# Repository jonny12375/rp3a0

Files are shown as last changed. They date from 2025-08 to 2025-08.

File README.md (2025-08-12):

# RP3A0 reverse engineering

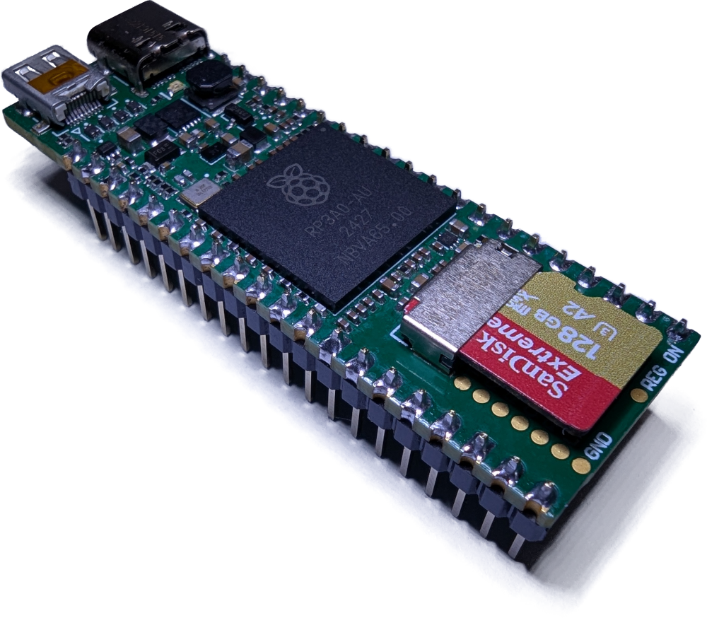
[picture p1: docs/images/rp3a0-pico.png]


This contains my attempts at reverse-engineering the RP3A0 SoC from the Raspberry Pi Zero 2W so I can place it on my own PCB.

I plan to eventually use this in another project, but for now I need a proof of concept. I decided to make the most cursed thing I could think of, Pi Pico sized board, but with a full Raspberry Pi processor on it. It has basically the same pinout as a Pi Pico, all the GPIOs that match up are in the same position. HDMI is sketchy, there's no Wi-Fi, and USB-C is a bit weird, but it boots and I can get it online. Check the [`breakout/rp3a0_mini`](breakout/rp3a0_mini) dir for this.

## Documentation:
* [`docs`](docs) - The pinout of the RP3A0 SoC, and how I reverse engineered it
* [`docs/reballing`](docs/reballing.md) - How to harvest the RP3A0 from a Raspberry Pi Zero 2W and prepare it for soldering onto a PCB
* [`breakout/rp3a0_mini`](breakout/rp3a0_mini) contains an Altium project for the RP3A0 Pico, a carrier board in almost the same form factor as the Pi Pico
* [`library`](library) contains an Altium library with the SoC footprint and the outline of the castellated pads for a Pi Pico

## Disclaimer
This was a stupid idea and you probably shouldn't do it. There are heaps of other Linux SoCs you can use, an especially ones that aren't a 21x21 BGA device with no public documentation. It's also not super easy to solder, so you might trash a couple parts trying to get it right.

## Thanks to...
* My coworkers for putting up with me asking questions about BGA reballing and PCB design
* Jeff Geerling ([YouTube](https://www.youtube.com/c/JeffGeerling), [website](https://www.jeffgeerling.com/)) for:
  * his blog post with an [X-Ray of the Pi Zero 2W](https://www.jeffgeerling.com/blog/2021/look-inside-raspberry-pi-zero-2-w-and-rp3a0-au) that inspired this project
  * being cool when I ambushed him at Open Sauce 2025 to show him my crazy project
  * being the first person to test out my prototype board, giving me feedback and providing some great photos for me to use
* Raspberry Pi for making such a great little SoC, and at least releasing _some_ schematics for it

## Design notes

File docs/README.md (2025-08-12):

# Reverse engineering the RP3A0

## tl;dr - RP3A0 pinout

The RP3A0 a 21x21 BGA package with 0.65mm pitch, outside dimensions are 15x15mm. I haven't measured the pad size accurately, but I'm using 0.3mm solder balls when reballing it.

Here's the pinout of the RP3A0 SoC (as far as I can tell). All the names here are ones I've given to the pins. They're labelled as to what they do on a Pi Zero 2W, not what the function is internally.
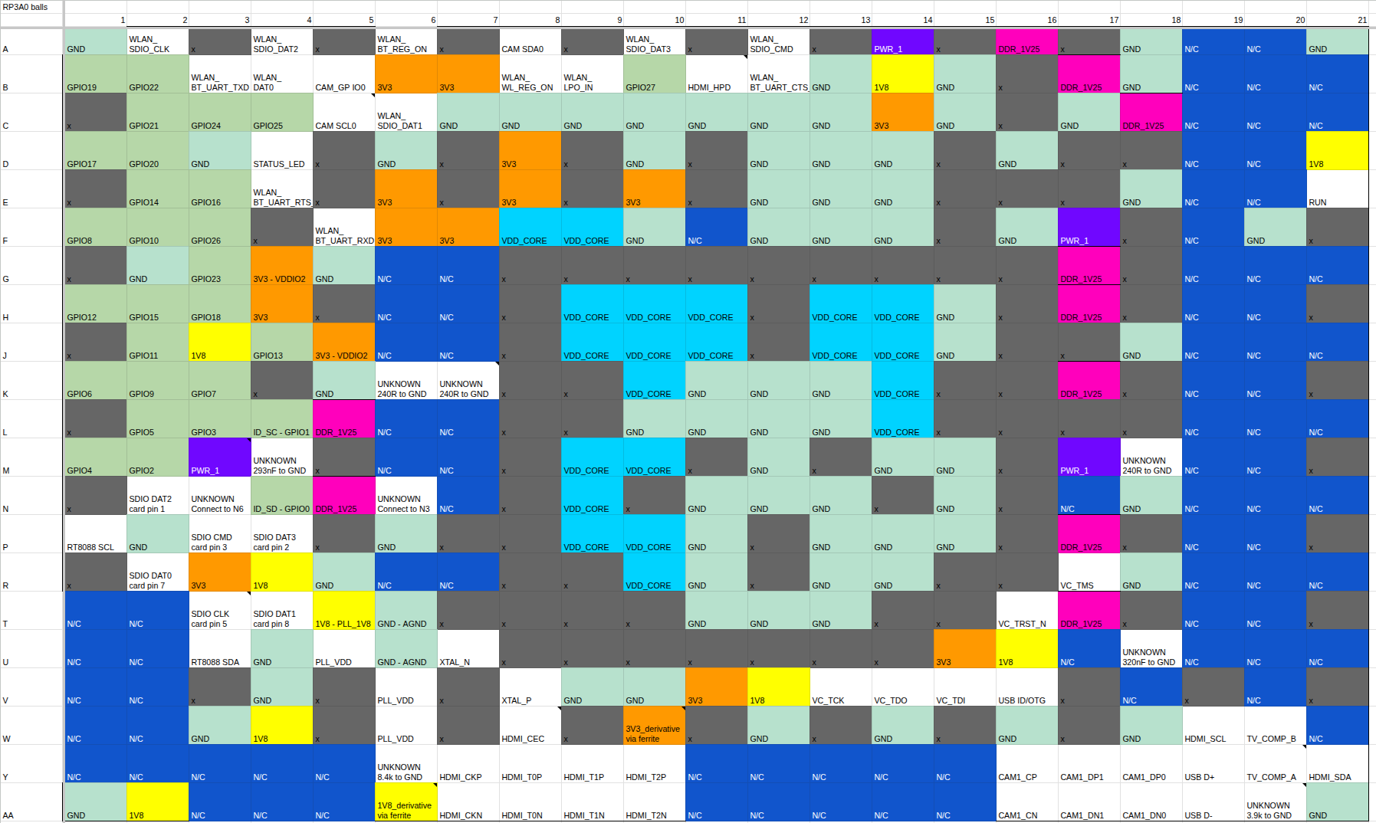
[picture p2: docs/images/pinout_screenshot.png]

You can check out the Google Sheet with the pinout here: [RP3A0 balls](https://docs.google.com/spreadsheets/d/1cQo1mM0g4L-HjAe8-86Zw-xbBoLv0I49Cb5mO69Yzt8/edit?usp=sharing) or check the schematics for my breakout board [`breakout/rp3a0_mini/outputs/rp3a0-pico-schematics-v1.1.pdf`](../breakout/rp3a0_mini/outputs/rp3a0-pico-schematics-v1.1.pdf).

There are a bunch of unknown pins, so all I've done is hooked them up in the same way that they are on the Pi Zero 2W. The reduced schematics that are published do show some pins on the SoC, so those were easy to label.

Note: Pins on a BGA are denoted with a letter and a number, where the letter is the row and the number is the column. BUT, not all letters are used when labelling BGA pins to avoid confusion. The letters `I, O, Q, S, X and Z` are skipped, and then it rolls over to `AAx`, `ABx`. This confused me at first when the reduced schematics had the crystal connected to U7 and V8 but from my pinout it was on Q7 and R8. 

Want to learn how to solder the RP3A0? Check out [reballing the RP3A0](reballing.md)

## Why?
There's another project I've been working on for years (that I'll probably document at some point in the future), but I wanted to add a linux processor to it. 
However it's pretty space constrained and I didn't want to have to do traces for DDR, so I was looking for an SoC that had a decent amount of RAM baked in, or a decent SoM. Unfortunately, most SoMs I found have parts on the other side as well, meaning I'd have to have a cutout in whatever board I was putting it on.

Here's a few of the options I was looking at:
* Allwinner F1C100s/F1C200s SoC
  * QFN package is easy to solder 
  * Doesn't have a huge amount of RAM (32MiB/64MiB)
* Rockchip RV1103/6 SoC
  * QFN package is easy to solder
  * Has a decent amount of RAM (128MiB)
  * Not a lot of software support, but I could probably get it working
* MangoPi mCore-R818 SoM
  * Powerful, heaps of RAM
  * Has parts on the other side so needs a cutout in the board
  * Pretty big at 32x32mm, hard to find that much space in a square in the form factor I need
* Pi Compute module
  * Very powerful
  * Gets pretty thick with the connectors
* Raspberry Pi Zero 2W
  * Fairly powerful
  * VERY well supported
    * Easy to build a kernel for it
    * Heaps of software support
  * Won't fit at all in the space I have
  * If only I could use the processor on its own...
* RP3A0
  * Fairly powerful
  * Has 512MiB of RAM baked in
  * VERY well supported
  * Only reduced schematics available
  * 21x21 BGA package, not easy to solder
  * Only available on the Pi Zero 2W
  * Sounds like a fun challenge though

## Equipment I used
* Hot air rework station: anything will be better than what I've got
* Soldering iron: Hakko FX-888D
* Flux: Chipquik NC191
* Hot plate: I got this one from AliExpress: [link](https://www.aliexpress.com/item/1005005576574932.html). I haven't tried the smaller USB-C powered ones, this one is pretty good, though it has some serious thermal mass so it takes a little bit to heat up, but also takes FOREVER to cool down.
* Microscope: I can't find the exact one I bought, but again from AliExpress: [link](https://www.aliexpress.com/item/1005008174025268.html). Having both HDMI and USB was super useful for this project. The HDMI output is much lower latency, so it's totally possible to look just at my monitor when soldering under it. The USB output just shows up as a webcam on a computer, so I used VLC to stream the video feed and used that to capture screenshots.
* Sandpaper: I used 800, 1200 and 2000 grit, but you could probably get away with just 800 and 1200
* Glass plate: I used an old glass 3D printer bed, but any flat piece of glass will do
* Tweezers: Mine are the ones that come in the iFixit Pro Tech Toolkit

## How?
There are only [reduced schematics](https://datasheets.raspberrypi.com/rpizero2/raspberry-pi-zero-2-w-reduced-schematics.pdf) available for the Pi Zero 2W, which fortunately gives all the details about the power supplies, but not much else. To figure out the rest I was going to have to follow the traces on the PCB. Unfortunately, it's a 6-layer PCB, so there's going to be a lot that I can't figure out without going in deeper. If I had a CNC mill I might have tried to use that to shave down the board, but surely just using sandpaper won't take too long, right?

I wanted to be able to keep track of all of the different parts on the board, just in case I needed to re-use or re-measure any of them. I printed out a photo of the board and covered it in double-sided tape, and put each part I took off the board back onto the same location on the board. I used hot air to remove the parts at the start, but it was definitely harder than expected given the lead-free solder that's used. I managed to pull some pads off the board when taking the SoC off, fortunately they weren't connected to anything. Later on in the project I bought a small hot-plate that made taking parts off MUCH easier.
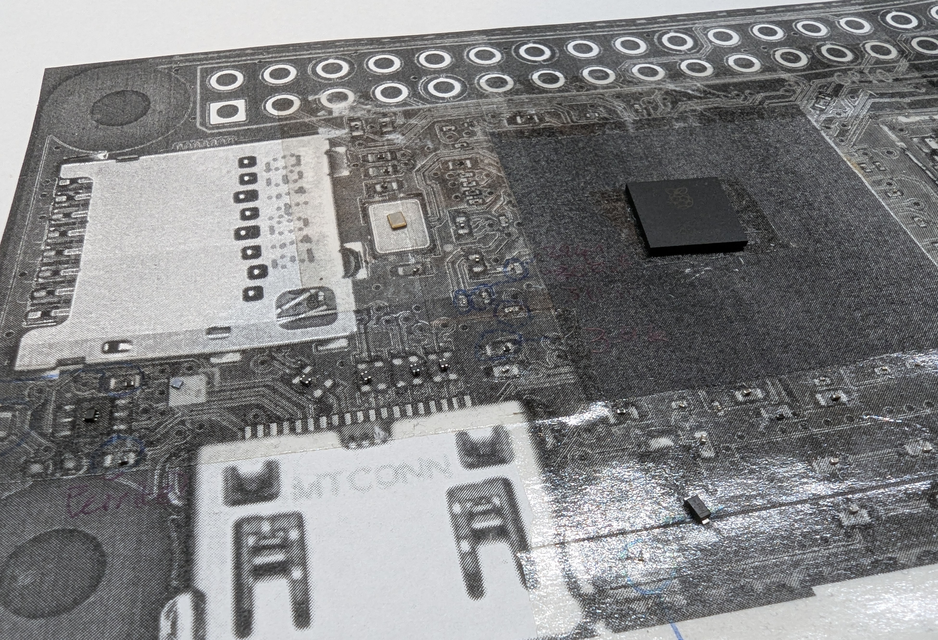
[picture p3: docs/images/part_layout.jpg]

My highly sophisticated parts organisation system. Some of passives are tiny 0201 packages, I definitely lost a few of them while trying to measure them, so I had to take a guess.

I started off with some other boards that I had lying around to test out the process. I figured I needed a super flat surface to start with, so I used an old glass 3d printer bed I had. I bought 800, 1200 and 2000 grit sandpaper from the hardware store, along with some gloves since I knew it was going to get messy. Since it's sanding fibreglass, you should be more careful than I was and wear a mask. Since I was wet sanding it didn't create a lot of dust in the air.
I cut out bits of the sandpaper, taped it down to the glass, wet the sandpaper and started sanding the board. At first I just needed to get through the soldermask on both sides to get a better look at the traces underneath, and that only took a couple minutes before all I had was bare copper.

To then get an image of the copper, I tried the flatbed scanner that's in my Brother printer, but it's resolution wasn't great. I probably could have worked out the traces from it, but it was still pretty blurry. The microscope I have only has a 27mmx15mm field of view at the lowest magnification, so I couldn't get a full image of the board at once. I ended up making a simple jig to hold the board in place with notches in it so I could move the board between the notches reliably to take a photo of one horizontal segment. Then I moved the board down a little bit leaving an overlap of about a third of the board, and took captures of the next horizontal segment.
I tried a bunch of tools that could supposedly do all the stitching for me, like Hugin and https://github.com/OpenStitching/stitching. However, I just couldn't get anything to work reliably, and I was spending more time than it would have taken me to just stitch it myself. Instead, I imported each image into GIMP then used the Unified Transform tool to rotate/scale/change perspective of each image to line up the vias from the microscope image with the vias in the image from the flatbed scanner. 

I changed between the sandpaper as I went depending on how much material I needed to remove. Usually the 800 grit was fine. It's quite a slow process, and also quite hard to get the board to sand down evenly. I was checking the board every so often, and if it was wearing unevenly I'd apply more pressure to an area, or even give the board a bit of a bend. It would keep its shape just enough focus on a particular area without sanding down areas that were already well exposed.

## Results
The process was very slow - I ended up sanding and capturing one layer per night after work. But the results are worth it! After stitching all the images together, I ended up with a full set of 6 layers of the Pi Zero 2W PCB. The stitching isn't perfect, but the main thing I wanted was to reliably have all the vias lined up so I'd be able to follow the traces between layers. I also made sure to capture the top layer with the soldermask sanded off, so I could see all the traces and pads clearly.
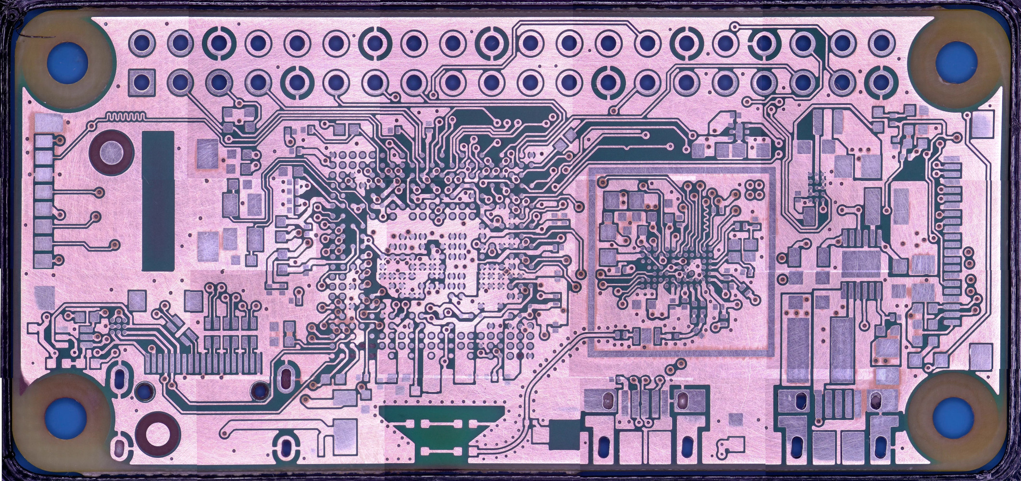
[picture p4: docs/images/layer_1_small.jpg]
The top layer with soldermask sanded off


High resolution layers - (~5MB JPGs)!
* [Top with soldermask and silkscreen](images/layer_1_soldermask.jpg)
* [Layer 1](images/layer_1.jpg)
* [Layer 2](images/layer_2.jpg)
* [Layer 3](images/layer_3.jpg)
* [Layer 4](images/layer_4.jpg)
* [Layer 5](images/layer_5.jpg)
* [Layer 6](images/layer_6.jpg)
* [Bottom with soldermask and silkscreen](images/layer_6_soldermask.jpg)

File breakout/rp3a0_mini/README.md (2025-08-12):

# RP3A0 Pico

This contains the Altium project for the RP3A0 Pico, a Pi Pico sized board with the RP3A0 SoC on it. 

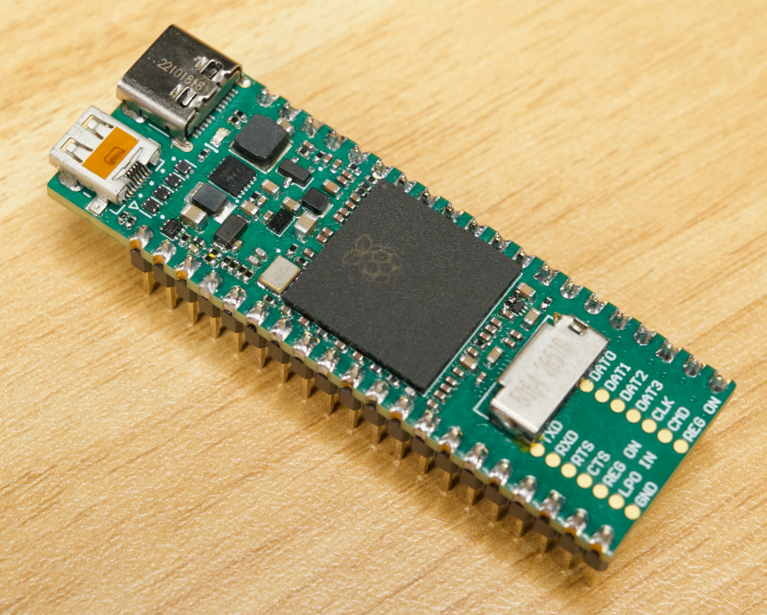
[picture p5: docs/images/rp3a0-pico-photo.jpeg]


## Goals
* Prove that I have the RP3A0 SoC pinout
* Create a board that could actually be useful where you need a more powerful processor in a small form factor
* Staying close to the Pi Pico form factor, with the same castellated pads and no parts on the underside

## Errata v1.1
This is definitely a V1 - this is the first board I've had built of this design.  
* I spent no time on the HDMI, so it doesn't work super well. I have managed to get 1080p@60Hz video out of it, but it didn't work well on some monitors. With some proper trace layout and impedance matching it should work better.
* The ports are far too close together, but I didn't have enough space if I wanted to keep the same width as a Pico. In the next revision I'm going to try out rotating the HDMI connector 90 degrees to point out the side.
* There is no Wi-Fi or Bluetooth. There's not a huge amount of space on the board, but I left test pads for all the signals from the RP3A0. It may be possible to transfer over the layout from the Pi Zero 2W but there would be no space for an on-board antenna. The part is a finer pitch than the RP3A0, so reballing it will be difficult.
* The ID pin that would normally go to the micro USB connector is only connected to a test pad on the underside. I'm not sure if this makes a big difference in reality, since I've been able to use it as a USB host just fine. In case you do need the functionality, you can bridge the pads of J4 on the bottom side to connect ID to GND.
* I haven't tested this in any Pi Pico breakout boards, so there's a chance some pins don't match up. I'd recommend checking the pinout against the schematic of the breakout board before plugging it in.
* I didn't connect VSYS to VBUS with a diode, so the 5V pin (pin 40) goes directly to the 5V rail. There's no overvoltage or reverse polarity protection. Also I didn't connect pin 39 (labelled VSYS on a Pico) to anything, so if something takes power from it, it won't work. You could bridge them together with solder.
* Not all the values on the schematics are correct, I've tried to update the BOM CSV with the notes I took when building the board

## Important links
* Schematic PDF - [outputs/rp3a0-pico-schematics-v1.1.pdf](outputs/rp3a0-pico-schematics-v1.1.pdf)
* Draftsman PDF - [outputs/rp3a0-pico-draftsman-v1.1.pdf](outputs/rp3a0-pico-draftsman-v1.1.pdf)
* Gerber files - [outputs/rp3a0-pico-gerbers-v1.1.zip](outputs/rp3a0-pico-gerbers-v1.1.zip)
  * I had this built by JLCPCB, remember to add the option for castellated pads on two sides.
* BOM CSV - [outputs/rp3a0-pico-bom-v1.1.csv](outputs/rp3a0-pico-bom-v1.1.csv)

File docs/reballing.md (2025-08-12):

# Harvesting and reballing the RP3A0 SoC

## Can I just buy the RP3A0?
No, you can't. The RP3A0 is not available for purchase separately, but you can harvest it from a Raspberry Pi Zero 2W.

## Harvesting the RP3A0
This is the process I followed. It might not be the best way to do it, but it worked for me. Don't @ me complaining about all the Pi boards you destroy trying to do this.

You're going to need:
* A hotplate or a hot air rework station
  * I used hot air for this initially, but once I got the hotplate, I found it much easier. The tiny USB-C powered ones are probably good enough
* A good soldering iron
* Good flux - e.g. Chipquik NC191
* Solder wick
* Tweezers and/or a vacuum pickup tool
* Solder balls - 0.3mm for the RP3A0. Make sure it's leaded solder, lead-free is much harder to work with
* Solder
* A reballing stencil - 0.65mm pitch, 21x21 BGA, 0.3mm balls
  * You could use one of those fancy ones that holds the IC in and collects all the solder balls, but I just used a small stencil from a pack on AliExpress 
* A microscope is super useful
* A donor Pi Zero 2W

1. Put the Pi Zero 2W on the hotplate and heat it up to about 230C. Adding some flux to the SoC should help it come off easier. If you're using hot air - you're going to need a lot of heat. Go slowly and try not to rip any pads off.
2. Use some tweezers or a vacuum pickup tool to try and lift the SoC off the board. 
3. Turn the hotplate off and let the SoC cool down.
4. Add some flux to the bottom of the SoC and clean up the solder off the pads with solder wick. Adding some leaded solder to the pads will make this easier. Make sure all the pads are clean and have no solder on them.
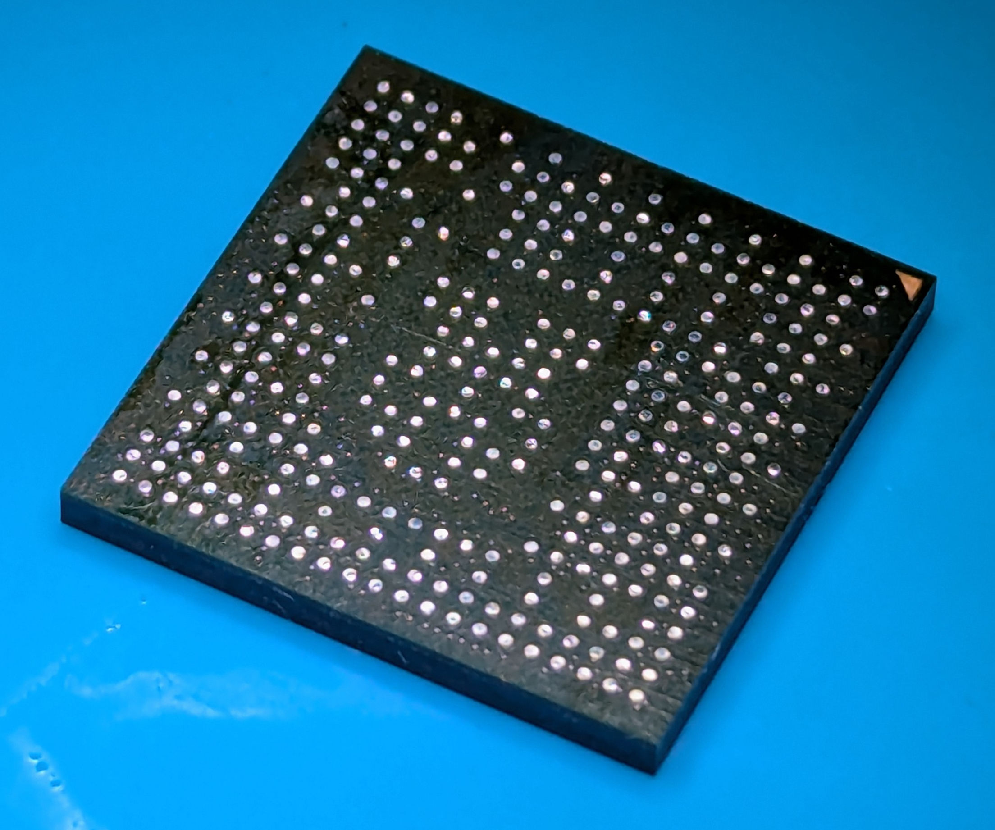
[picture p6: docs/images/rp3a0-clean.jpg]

It should look something like this
5. Apply a VERY thin layer of flux to the bottom of the SoC, and then place it on the stencil. Line up the holes in the stencil with the pads on the SoC.
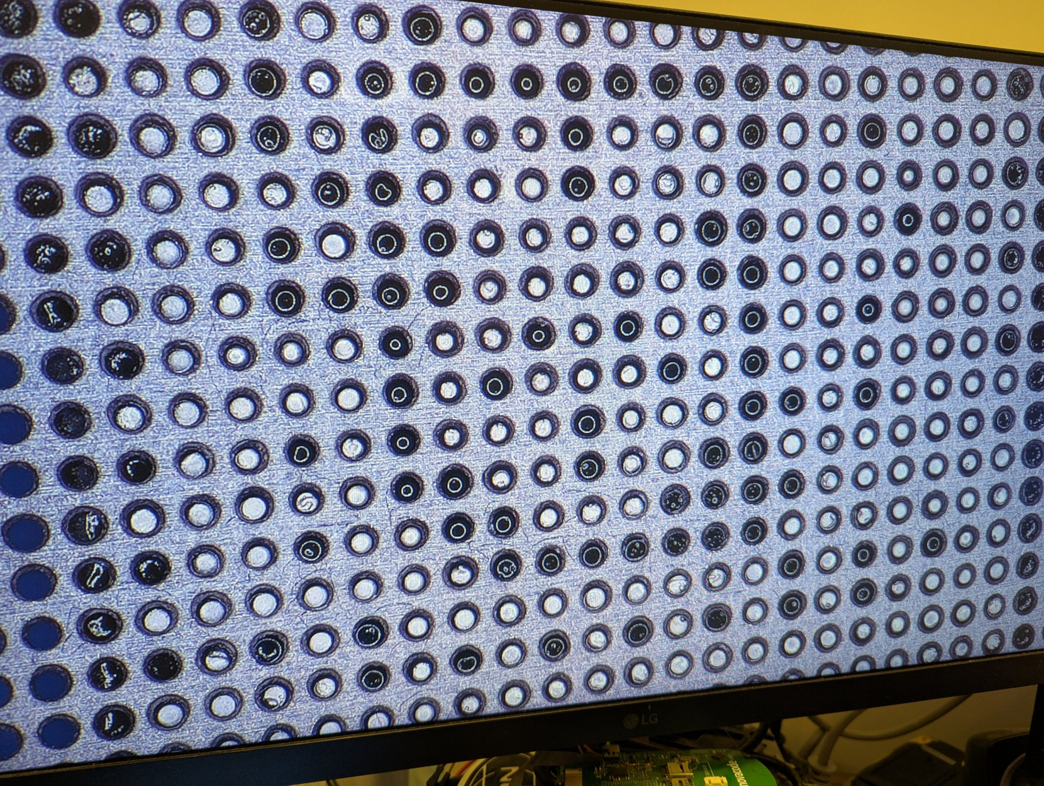
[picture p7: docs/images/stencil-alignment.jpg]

6. My flux was tacky enough to hold the stencil in place, but if yours isn't, you can use some tape to hold the SoC in place.
7. Find a shallow dish to put the stencil in. This is to catch all the solder balls that fall out.
8. Put the stencil in the dish with the holes facing up, and sprinkle some solder balls into the holes. Shake the stencil gently to spread the balls out. A card is also useful here to distribute them, but it also makes it easy to feel where there are two balls in one hole.
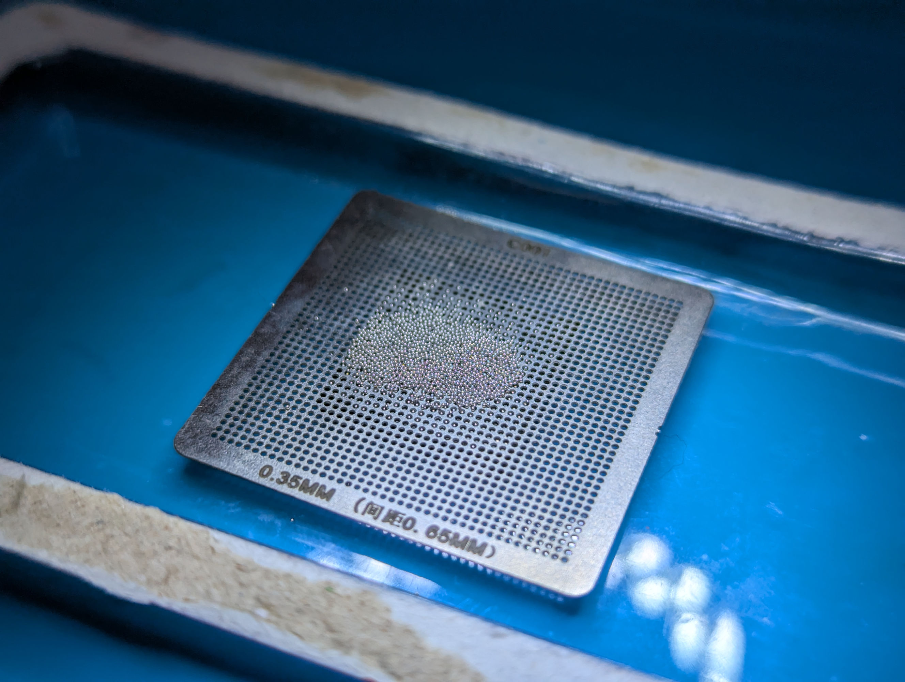
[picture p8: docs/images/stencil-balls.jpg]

9. You should only have one ball in each hole. If there is more than one, you'll end up with a pad that's got too much solder on it, and it will either lift the part up so it doesn't solder correctly, or cause a short.
10. Put the SoC (still stuck to the stencil) on the cold hotplate with the balls up, and turn the hotplate on to about 200C. You should see the solder balls melt and drop into place. If any don't drop into place, you may be able to carefully poke them in with tweezers. If the flux bubbles up and sends the balls everywhere, then you put too much flux on and you'll need to start again.
11. Once all the balls are in place, turn the hotplate off and let it cool down.
12. VERY carefully peel the stencil off the SoC. Don't force it if it's not coming, you may be able to heat it up a little bit to make the flux more liquid.
13. Inspect the SoC to make sure all the balls are in place and there are no shorts. If there's a ball missing, you're going to have to start again.
14. There will likely be some balls stuck to the SoC with flux that aren't supposed to be there. Using a little bit of Isopropyl alcohol and a toothbrush, gently brush the bottom of the SoC to remove them. You can refer to the pinout above to see which pads are supposed to have solder.

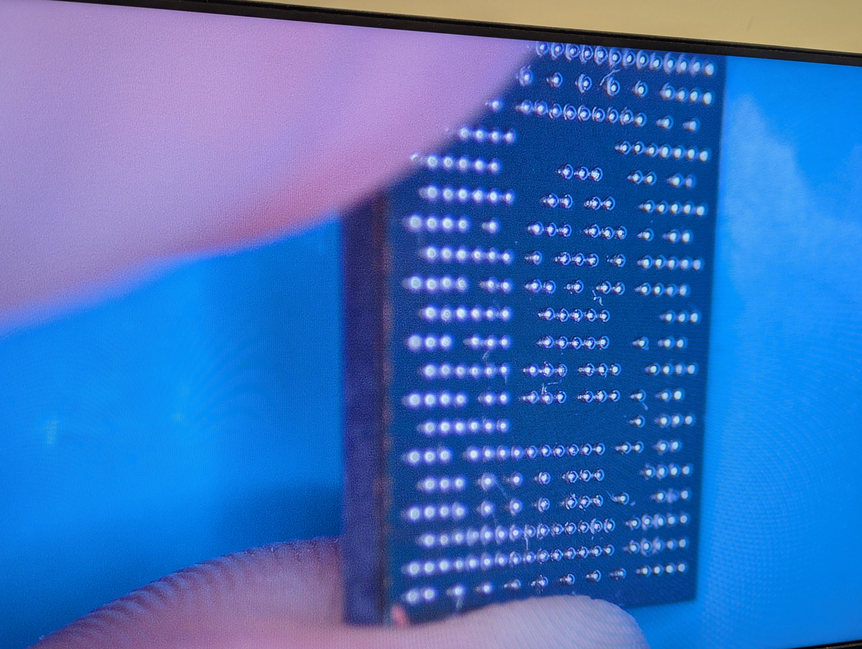
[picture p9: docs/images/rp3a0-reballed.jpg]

Great, now you have a re-balled RP3A0 SoC!

## Soldering the RP3A0

1. Clean the pads on the PCB, if there's solder, clean it all off with solder wick.
2. Add a small layer of flux to the area
3. Place the RP3A0 on the pads, making sure to line it up as close as you can. When reflowing it will move into place, but only if it's close in the first place.
4. Put the PCB on the hotplate and turn it on to about 200C.
5. As it heats up, keep an eye on it. The flux should start bubbling and smoking, then hopefully the RP3A0 will jump into place. 
6. If you want, you can VERY carefully give it a little poke with tweezers to check it's in place. If it is, turn the hotplate off and let it cool down.
7. Good luck! If it didn't work, then you get to do it all again.

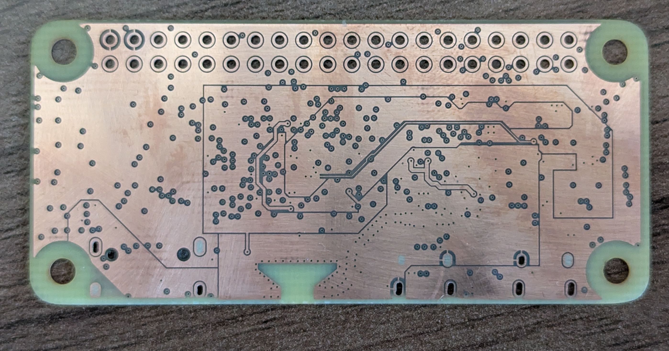
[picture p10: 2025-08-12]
docs/images/pcb_sanded.jpg

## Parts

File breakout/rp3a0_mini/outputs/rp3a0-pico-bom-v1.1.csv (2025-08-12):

Name | Designator | Quantity | Value | Footprint | Description | Comment | Link
Cap | C1, C2, C5, C8, C18, C20, C21, C22, C23, C24, C26, C27, C28, C29, C30, C31, C32, C33, C34, C35, C37, C39, C40, C41, C42, C44, C45, C46 | 28 | 220n | CAP-0402 | Capacitor 0402
Cap | C3, C4, C11, C13, C16, C17 | 6 | 10u | CAP-0603 | Capacitor 0603
Cap | C6, C9 | 2 | 18p | CAP-0402 | Capacitor 0402
Cap | C7, C10 | 2 | 1u | CAP-0402 | Capacitor 0402
Cap | C12, C14 | 2 | 47u | C0805 NP | Capacitor 0805 |  | https://www.lcsc.com/product-detail/C16780.html
Cap | C15, C19, C47 | 3 | 100n | CAP-0402 | Capacitor 0402
Cap | C25 | 1 | 100p | CAP-0402 | Capacitor 0402 | Not super sure on this value, 100pF works
Cap | C36, C38, C43 | 3 | 4.7u | CAP-0603 | Capacitor 0603 |  | https://www.lcsc.com/product-detail/C1705.html
SMD_LED | D1 | 1 |  | LED_0603 | 0603 LED
DFLS130LQ-7 | D2 | 1 |  | DIO_DFLS130LQ-7 | Diode Schottky 1A 30V PowerDI 123 | Diodes Inc DFLS130LQ-7
EXC-24CG900U | FL1, FL2, FL3, FL4 | 4 |  | FIL_EXC24CB102U | Common mode Filters(for Gbps) | Couldn’t find the original part I spec’d, switched to PANASONIC EXC24CH900U | https://www.lcsc.com/product-detail/C236275.html
MOLEX-0475710001 | J1 | 1 |  | MOLEX_0475710001 | 9 _8 + 1_ Position Card Connector Secure Digital - microSD™ Surface Mount, Right Angle Gold | Couldn’t find the original part, switched to Molex 473092651 | https://www.lcsc.com/product-detail/C587826.html
MOLEX-467652301 | J2 | 1 |  | MOLEX_467652301 | 0.40mm Pitch Micro HDMI Connector, Right-Angle Receptacle, Surface Mount |  | https://www.lcsc.com/product-detail/C6961796.html
105450-0101 | J3 | 1 |  | MOLEX_105450-0101 | USB-C, USB 3.1 Gen 2, Receptacle Connector 24 Position Surface Mount, Right Angle; Through Hole |  | https://www.digikey.com/en/products/detail/molex/1054500101/5843890
INDUCTOR | L1 | 1 | 470nH | INDC2016X100N | SRP2010-R47M inductor |  | https://www.digikey.com/en/products/detail/bourns-inc/srp2010-r47m/4876856
INDUCTOR | L2 | 1 | 4.7uH | INDP4040X180N | BOURNS SRN4030HA-4R7Y |  | https://www.lcsc.com/product-detail/C5926030.html
INDUCTOR | L3 | 1 | 2.2uH | INDP2622X120N | BOURNS SRN2512-2R2M |  | https://www.lcsc.com/product-detail/C2041574.html
INDUCTOR | L4, L5, L6 | 2 | 220R | CAP-0402 | Ferrite bead SMD |  | https://www.lcsc.com/product-detail/C85813.html
DMG2305UX-7 | Q1 | 1 |  | SOT91P240X110-3N_DMG2305UX-7 | DIODES DMG2305UX-7 P-Channel 20V 4.2A _Ta_ 1.4W _Ta_ Surface Mount SOT-23 |  | https://www.lcsc.com/product-detail/C150470.html
Res SMD | R1, R2, R21, R22, R23, R24 | 6 | 1k8 | RES-0402-SML | Resistor 0402
Res SMD | R3, R19, R20 | 3 | 100k | RES-0402-SML | Resistor 0402
Res SMD | R4 | 1 | 470k | RES-0402-SML | Resistor 0402
Res SMD | R5 | 1 | 82k | RES-0402-SML | Resistor 0402
Res SMD | R6 | 1 | 10k | RES-0402-SML | Resistor 0402
Res SMD | R7, R15, R25 | 3 | 47k | RES-0402-SML | Resistor 0402
Res SMD | R8 | 1 | 18k | RES-0402-SML | Resistor 0402
Res SMD | R9, R10 | 2 | 5.1k | RES-0402-SML | Resistor 0402
Res SMD | R11 | 1 | 470R | RES-0402-SML | Resistor 0402
Res SMD | R12, R13, R18 | 3 | 240R | RES-0402-SML | Resistor 0402
Res SMD | R14 | 1 | 33R | RES-0402-SML | Resistor 0402
Res SMD | R16 | 1 | 3.9k | RES-0402-SML | Resistor 0402
Res SMD | R17 | 1 | 1K | RES-0402-SML | Resistor 0402
RP3A0 | U1 | 1 |  | RP3A0-BGA | RP3A0-AU SoC | Only available on Pi Zero 2W boards, needs reballing after desoldering | https://www.raspberrypi.com/products/raspberry-pi-zero-2-w/
RT9081A-1BGQZA(2) | U2 | 1 |  | VREG_RT9081A_1BGQZA(2) | RT9081A-1BGQZA(2) Linear Voltage Regulator IC 1 Output 500mA 6-ZADFN (1.2x1.2) | Make sure you buy the 1.25V fixed regulator | https://www.digikey.com/en/products/detail/richtek-usa-inc/rt9081a-1bgqza-2/6676758
RT8088AWSC | U3 | 1 |  | 15B_WLCSP_1.31x2.11 | RT8088AWSC Buck Switching Regulator IC Positive Programmable 0.6V 1 Output 3A 15-UFBGA, WLCSP |  | https://www.digikey.com/en/products/detail/richtek-usa-inc/RT8088AWSC/5880503
PAM2306AYPKE | U4 | 1 |  | SON45P300X300X80-13N | PAM2306AYPKE Buck Switching Regulator IC Positive Fixed 1.8V, 3.3V 2 Output 1A 12-WFDFN Exposed Pad |  | https://www.lcsc.com/product-detail/C508236.html
DMG1024UV-7 | U5 | 1 |  | SOT50P162X60-6N | Dual N-Ch Enhancement MOSFET SOT-563 | Diodes Inc DMG1024UV-7 | Used DMN2004VK | https://www.lcsc.com/product-detail/C145115.html
ECS-192-18-33-JGN-TR | Y1 | 1 |  | XTAL_ECS-192-18-33-JGN-TR | 19.2MHz Crystal Oscillator |  | https://www.digikey.com/en/products/detail/ecs-inc/ECS-192-18-33-JGN-TR/6821628

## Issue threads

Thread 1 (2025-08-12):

First Prototype - Bringup issues

geerlingguy, 2025-08-12:
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

Just wanted to document here, since that way it can be documented _somewhere_. I was excited to receive a prototype from @jonny12375 at Open Sauce, and I have been testing it at my desk here:

- HDMI port is not functional (known issue)
- HDMI port and USB-C port are a little close together, meaning most of my plugs interfere with each other if I plug them both in at the same time (though some plugs are slim enough to work)
- 5V power via USB-C PD, USB-A to C, and direct to the 5V/GND pins via DC power supply worked fine, board consumed between 100-400 mA in my brief testing.
- Tried booting Pi OS 32-bit and 64-bit Lite and Desktop editions from a 32 GB microSD card, and it seemed to boot, but UART console would output nothing, but eventually after almost exactly 34 seconds every time, the kernel log would spit out 'rebooting' and it would restart.
- If I plugged my Debug Probe into the Pico's standard UART TX/RX pins, I would get some gibberish, so it *seems* like those pins ([pins 1/2 and GND](https://pico.pinout.xyz)) do something, but they didn't provide clean text output like GP14/GP15 (which are the [default on Pi GPIO](https://pinout.xyz))
- The SoC heated up to 55-58°C during this boot-and-reboot cycle, and the board was warm to the touch. Not much ground plane to dissipate the heat on there!

jonny12375, 2025-08-13:
Thanks for the submission and the coverage, @geerlingguy!

* I never managed to get HDMI working on the board you've got, but I've built up another one and I was able to get 1080p@60Hz out, but it definitely wasn't reliable. The routing of the HDMI traces is FAR from optimal, but I'm planning to fix that up on the next revision. I'll also try rotating the HDMI connector to point out the side to give a little more space.
* I'm going to flash clean Pi OS to an SD card and see if I can replicate the rebooting issue. The fact that it's printing that message out indicates the board has probably detected that somethings not right. Maybe related to the WiFi/BT IC being absent.
* The RP2040/2350's mapping for connecting peripherals to pins is far more configurable than the RP3A0. I initially opted for matching the GPIO numbers up instead of putting putting peripherals like UART and I2C on certain pins. This may make it hard if a breakout board is expecting UART or another peripheral like I2C or SPI on particular pins. I'll see whether there's a better layout to increase compatibility.
* GP0 and GP1 on the Pi Zero are ID_SD and ID_SC, on boot the RP3A0 tries to communicate using I2C on those pins to try and auto detect a HAT, so it makes sense you'd see something show up when connecting a UART adapter. Those pins aren't going to be very useful in a Pico form factor, so I might remove them if I shuffle the other pins around.

Tiersten, 2025-08-17:
> I never managed to get HDMI working on the board you've got, but I've built up another one and I was able to get 1080p@60Hz out, but it definitely wasn't reliable.

Y6 is HDMI_REF. R17 should be 8.4K but your BOM has 1K.

W10 is HDMI_3V3.
AA6 is HDMI_1V8.

K6/K7/M18 is ZQ/ZQ1 for SoC/RAM.

AA20 is USB_REF. C25 is 100pF.

zeankundev, 2025-09-06:
I think what @geerlingguy said that HDMI wasn't working, and after examination, those weren't routed in a differential pair manner. Looking forward on the next fix 😉

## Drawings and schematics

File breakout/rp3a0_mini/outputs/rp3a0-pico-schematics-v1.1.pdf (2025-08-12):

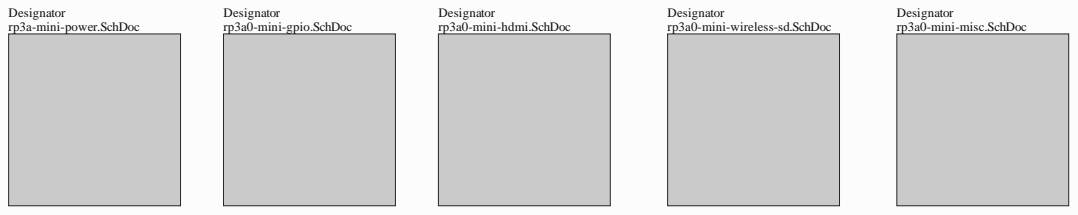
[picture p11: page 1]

Designator
rp3a0-mini-wireless-sd.SchDoc

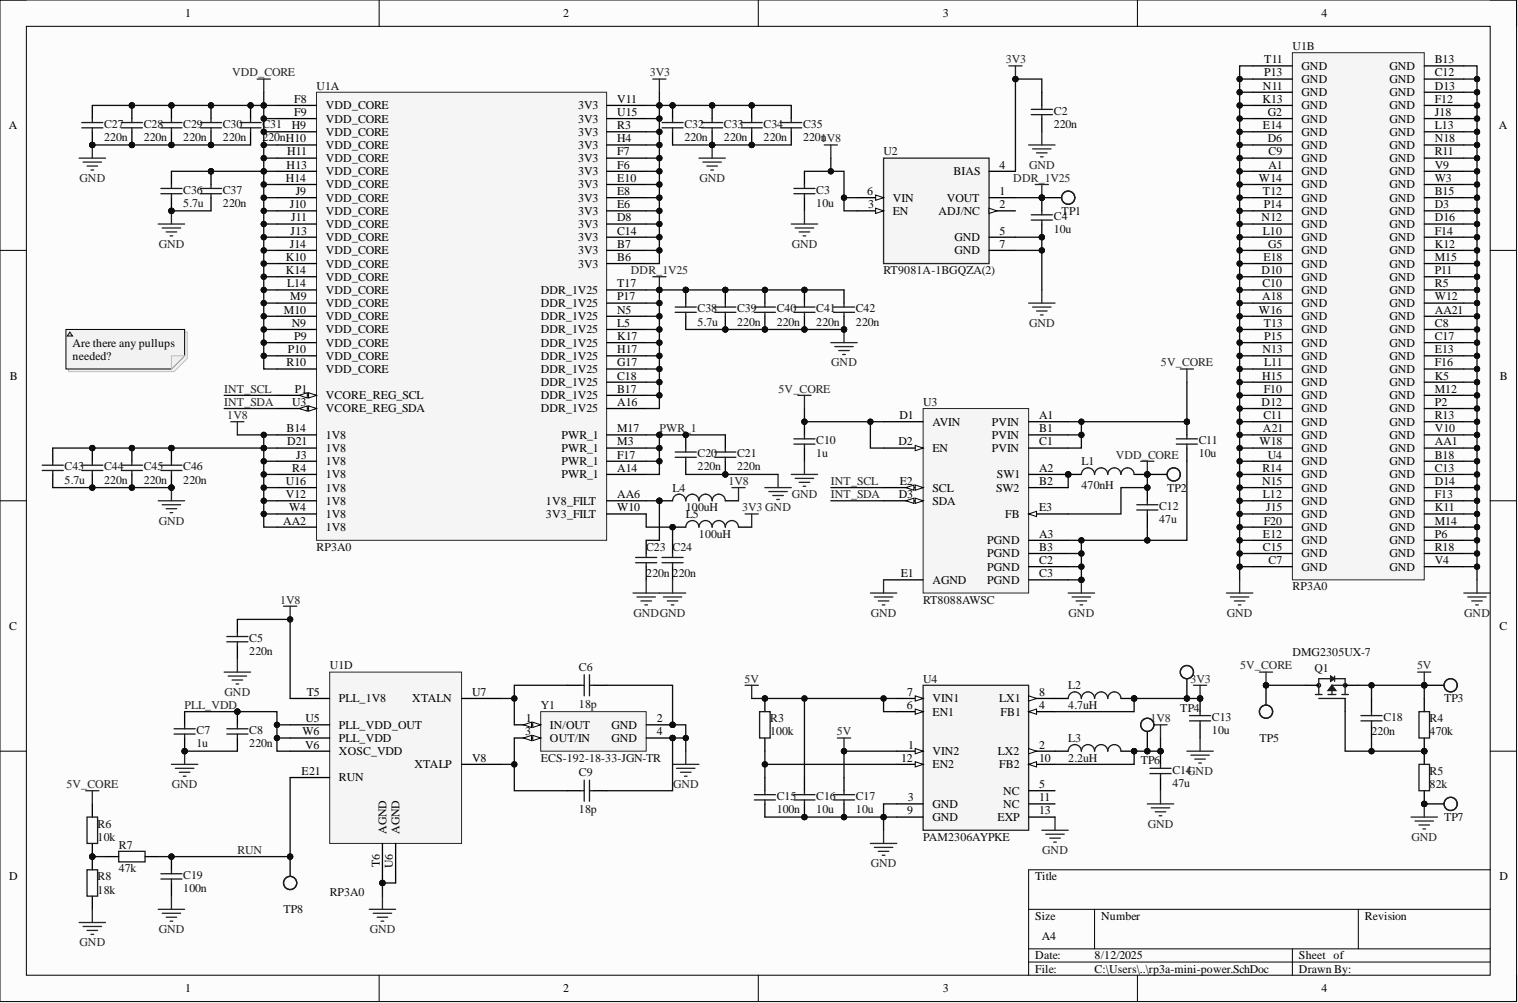
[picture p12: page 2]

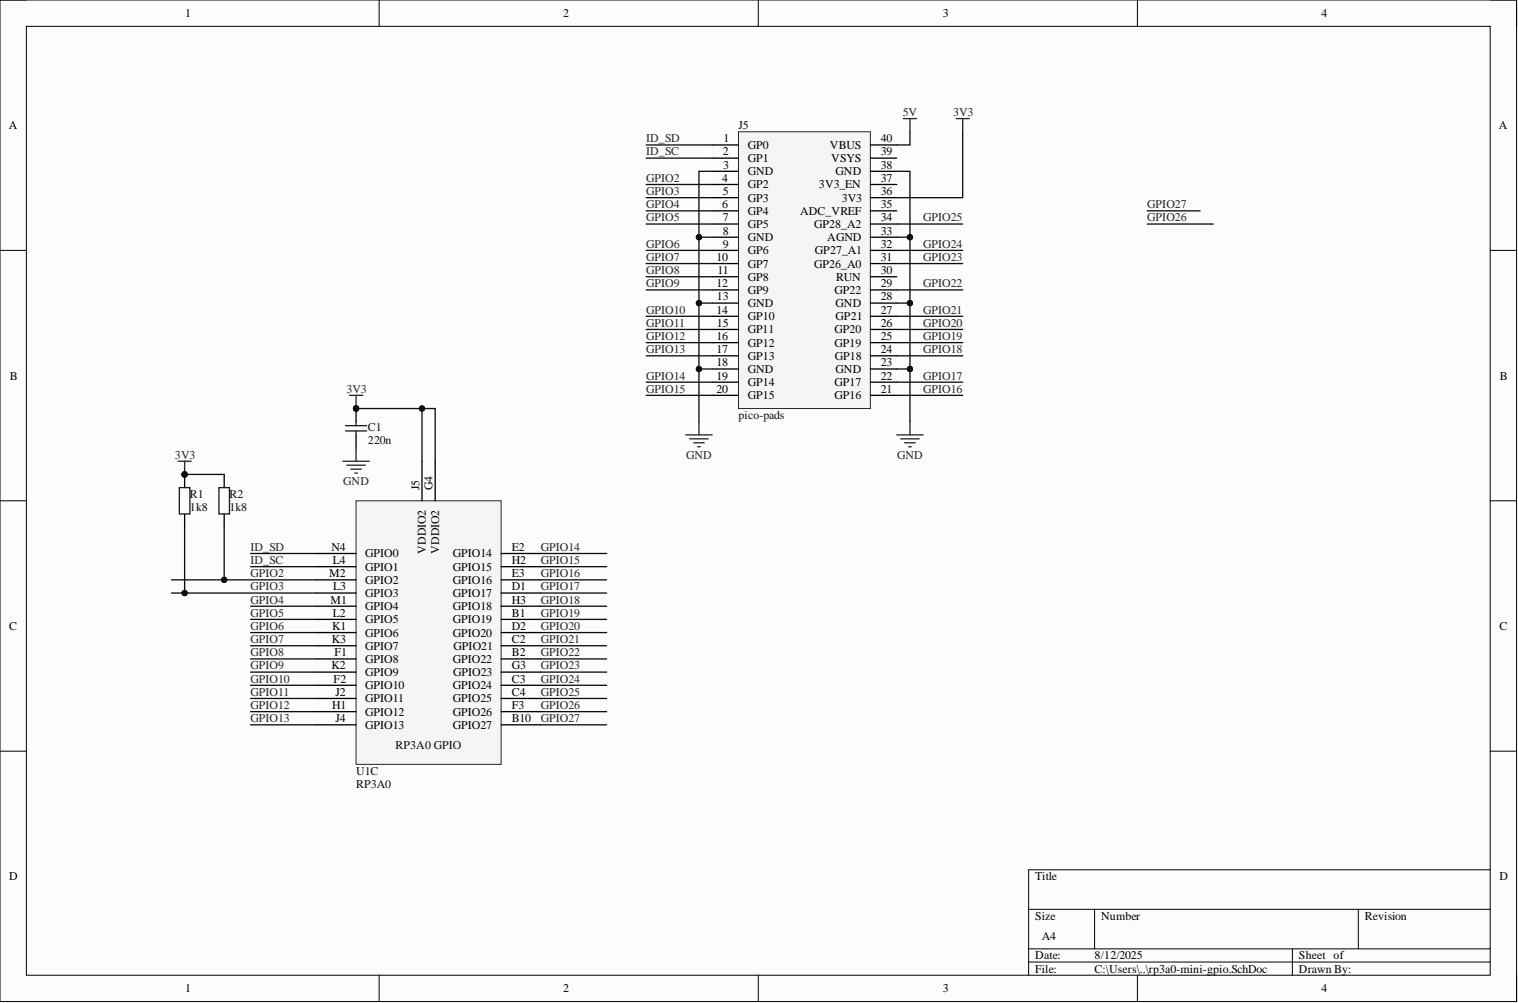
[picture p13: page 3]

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
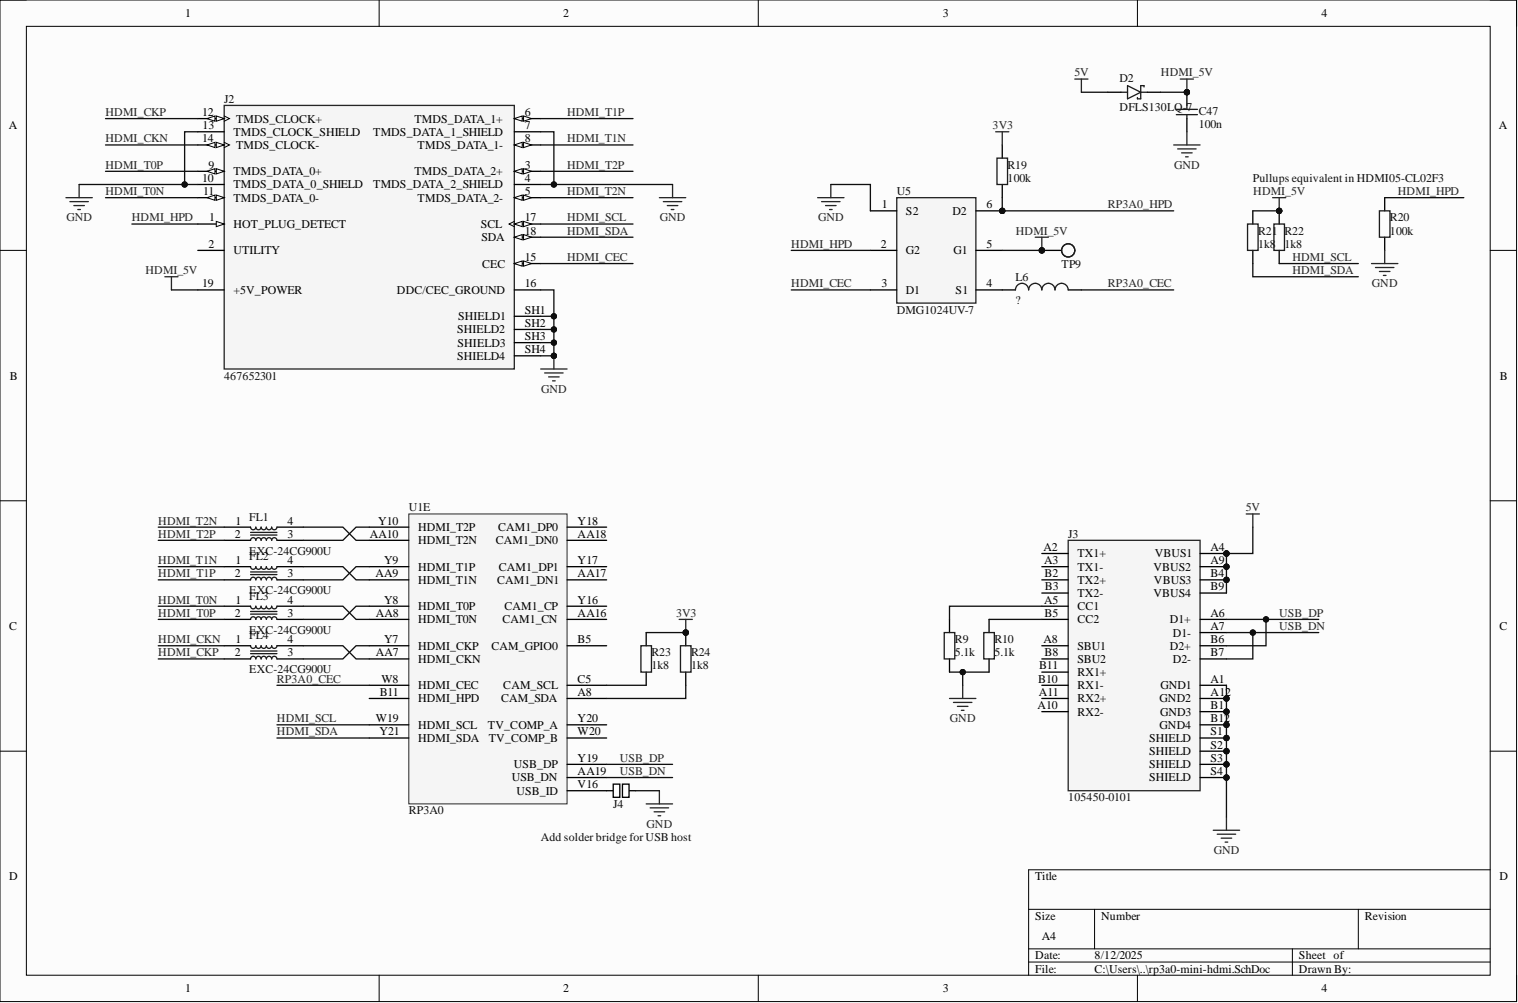
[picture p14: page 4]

Add solder bridge for USB host

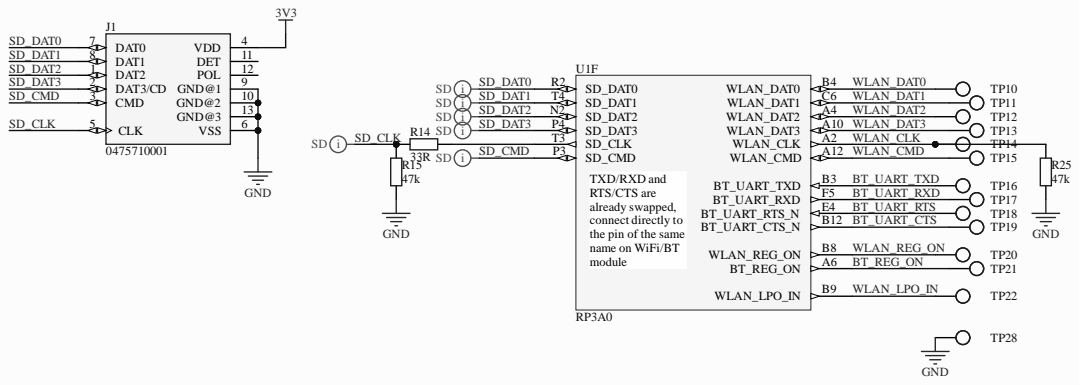
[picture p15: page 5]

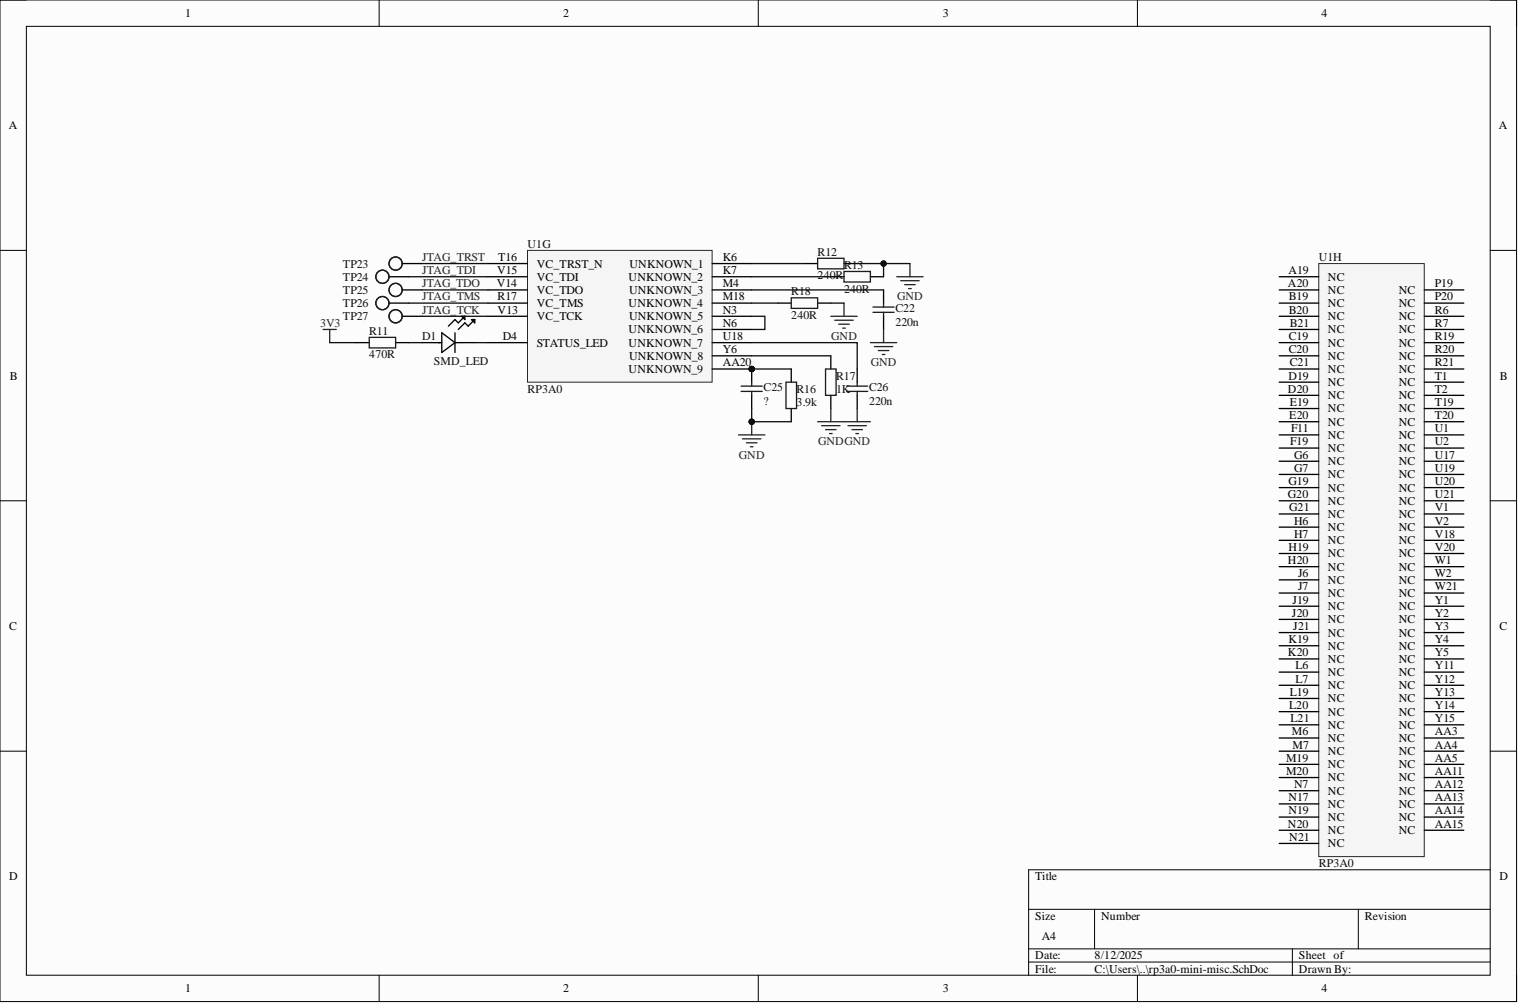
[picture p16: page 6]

Y 6
A A 2 0

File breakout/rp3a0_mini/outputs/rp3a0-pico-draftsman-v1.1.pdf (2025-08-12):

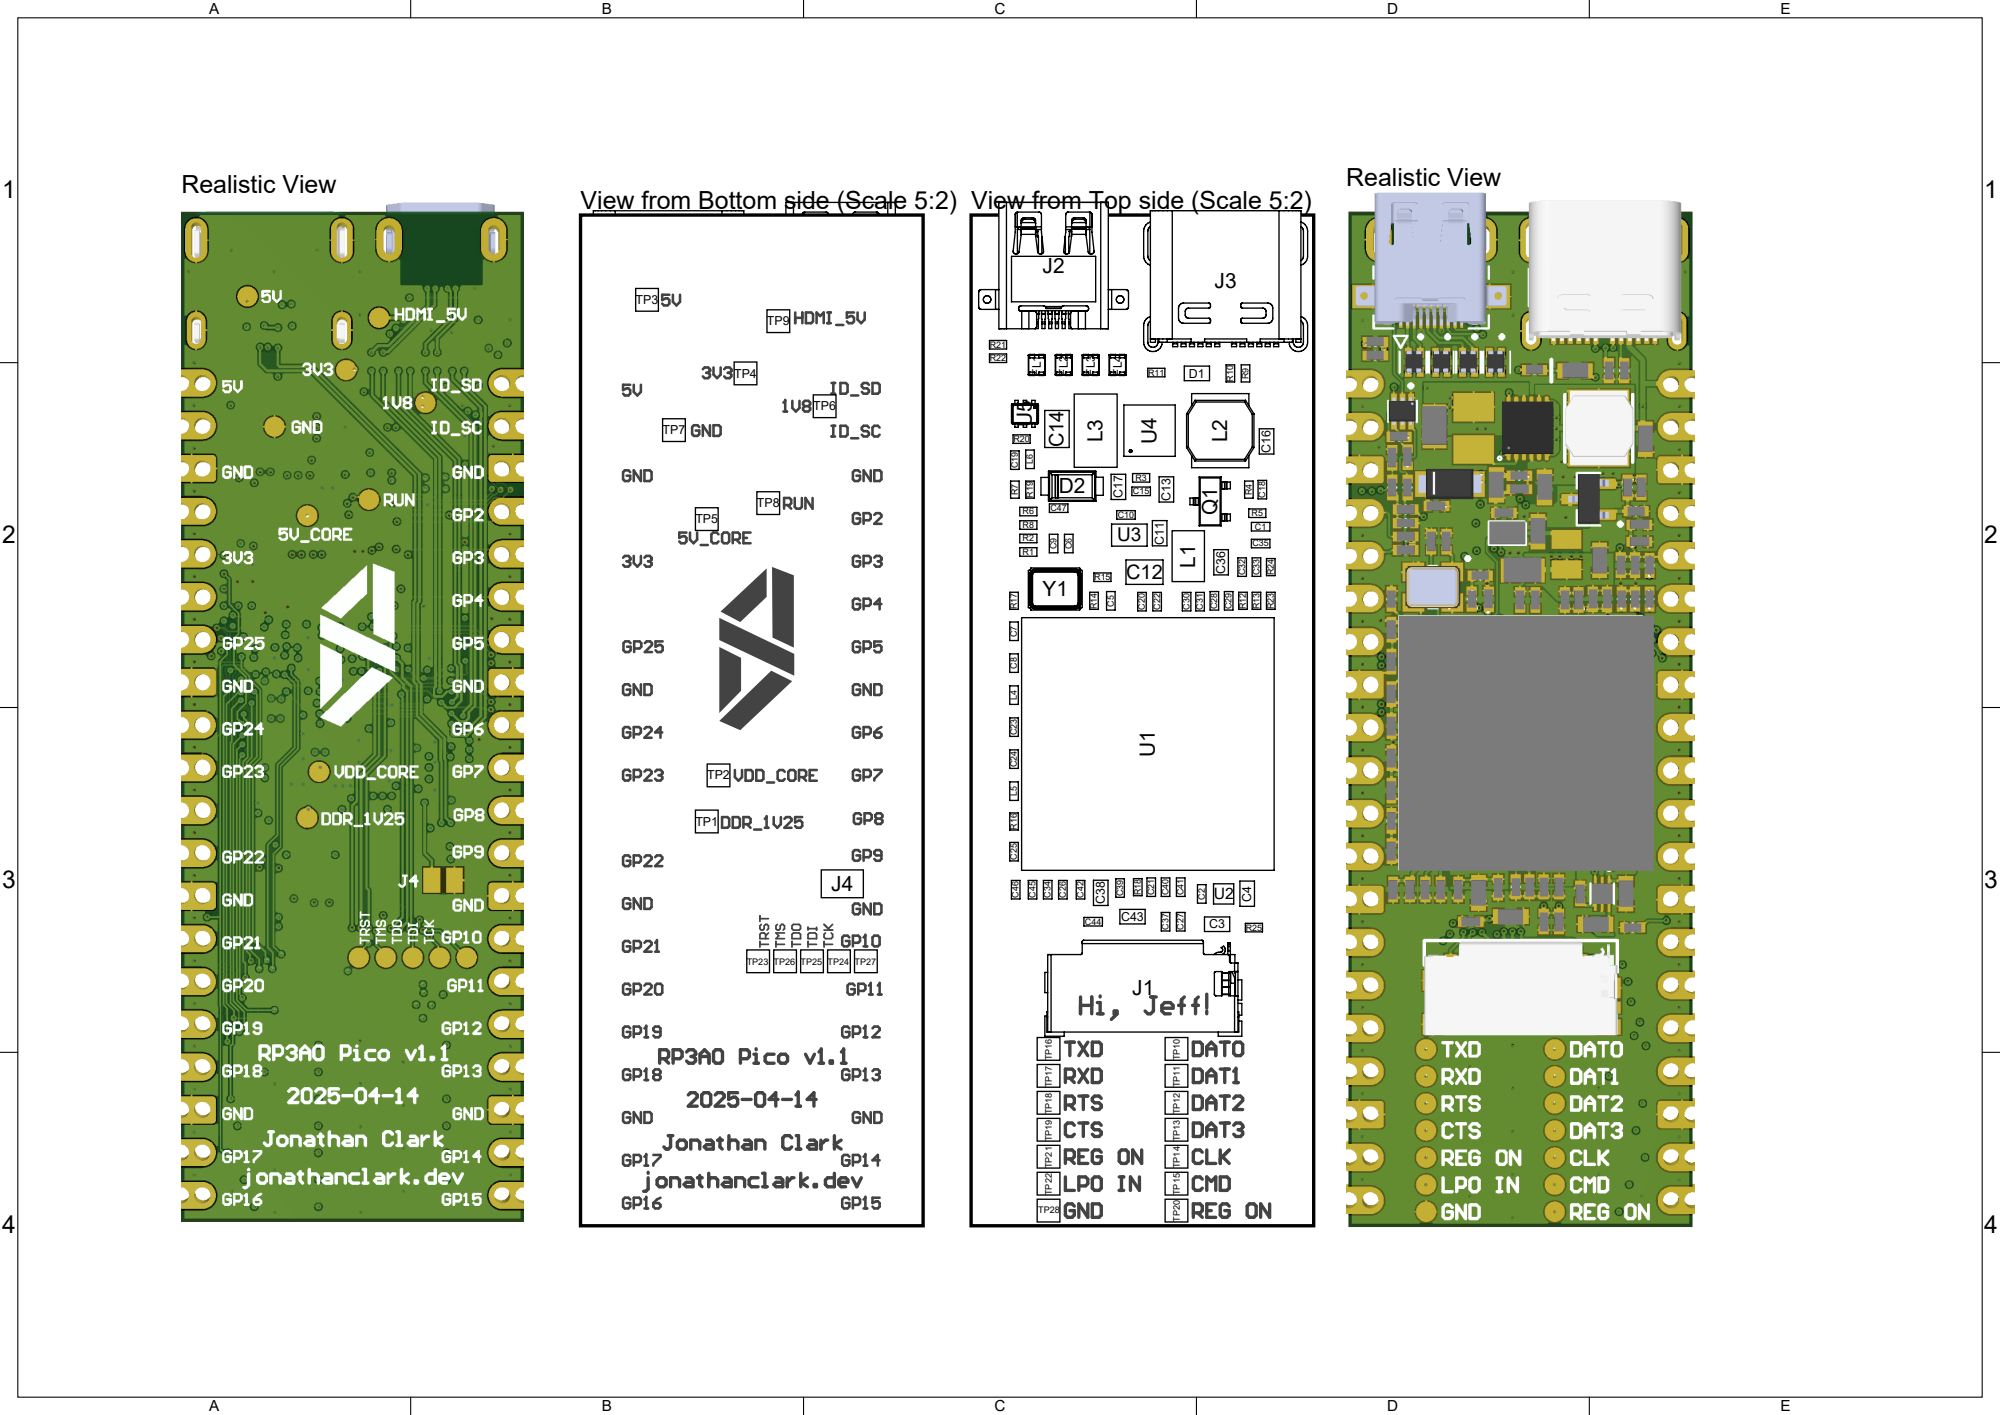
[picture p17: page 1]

View from Bottom side (Scale 5:2)

View from Top side (Scale 5:2)

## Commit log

2025-03-09 Add RP3A0 schematic lib/footprint
2025-03-09 Start RP3A0-mini
    [rp3a-mini-power.SchDoc, rp3a0-mini-gpio.SchDoc, rp3a0-mini-hdmi.SchDoc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]
2025-03-30 RP3A0 pico layout progressing
    [rp3a-mini-power.SchDoc, rp3a0-mini-gpio.SchDoc, rp3a0-mini-hdmi.SchDoc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]
2025-04-13 Finished - as shipped to JLC 2025-04-12
    [rp3a-mini-power.SchDoc, rp3a0-mini-hdmi.SchDoc, rp3a0-mini-misc.SchDoc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]
2025-04-13 Minor component value fixes
    [rp3a-mini-power.SchDoc, rp3a0-mini-misc.SchDoc, rp3a0_mini.PrjPcb]
2025-04-14 Minor tweaks from JLC, v1.1 2025-04-14
    Need 0.1mm clearance, fix resulting issues
    Fix hole size due to hole-hole clearance
    [rp3a0_mini.PrjPcb]
2025-08-12 Add docs
    [rp3a0-pico-bom-v1.1.csv]
